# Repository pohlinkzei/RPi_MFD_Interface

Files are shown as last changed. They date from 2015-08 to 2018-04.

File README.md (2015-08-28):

# RPi_MFD_Interface
Interface between RaspberryPi and VW MFD Radio Navigation System

The RPi_MFD_Interface is a Atmega16-based device to connect the
RaspberryPi with the CarAudio head unit. Its main purpose is to read the
buttons of the car audio and send it to the pi.  The second purpose is
to power the pi with control over booting up and shutting down of the
raspberry pi to prevent it killing the cars battery.

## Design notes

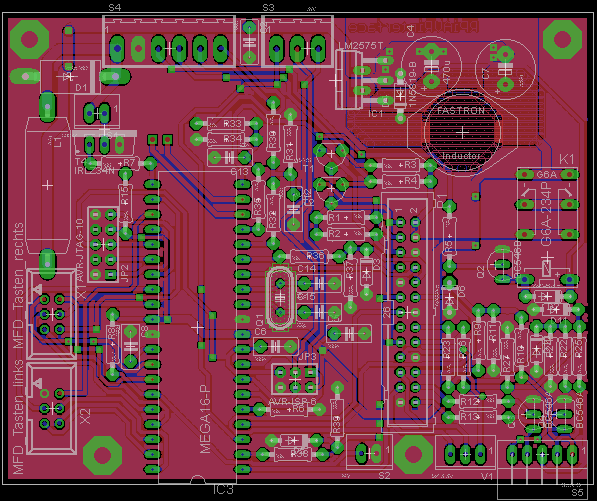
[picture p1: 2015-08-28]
layout/mega16_spg5Vonly.png

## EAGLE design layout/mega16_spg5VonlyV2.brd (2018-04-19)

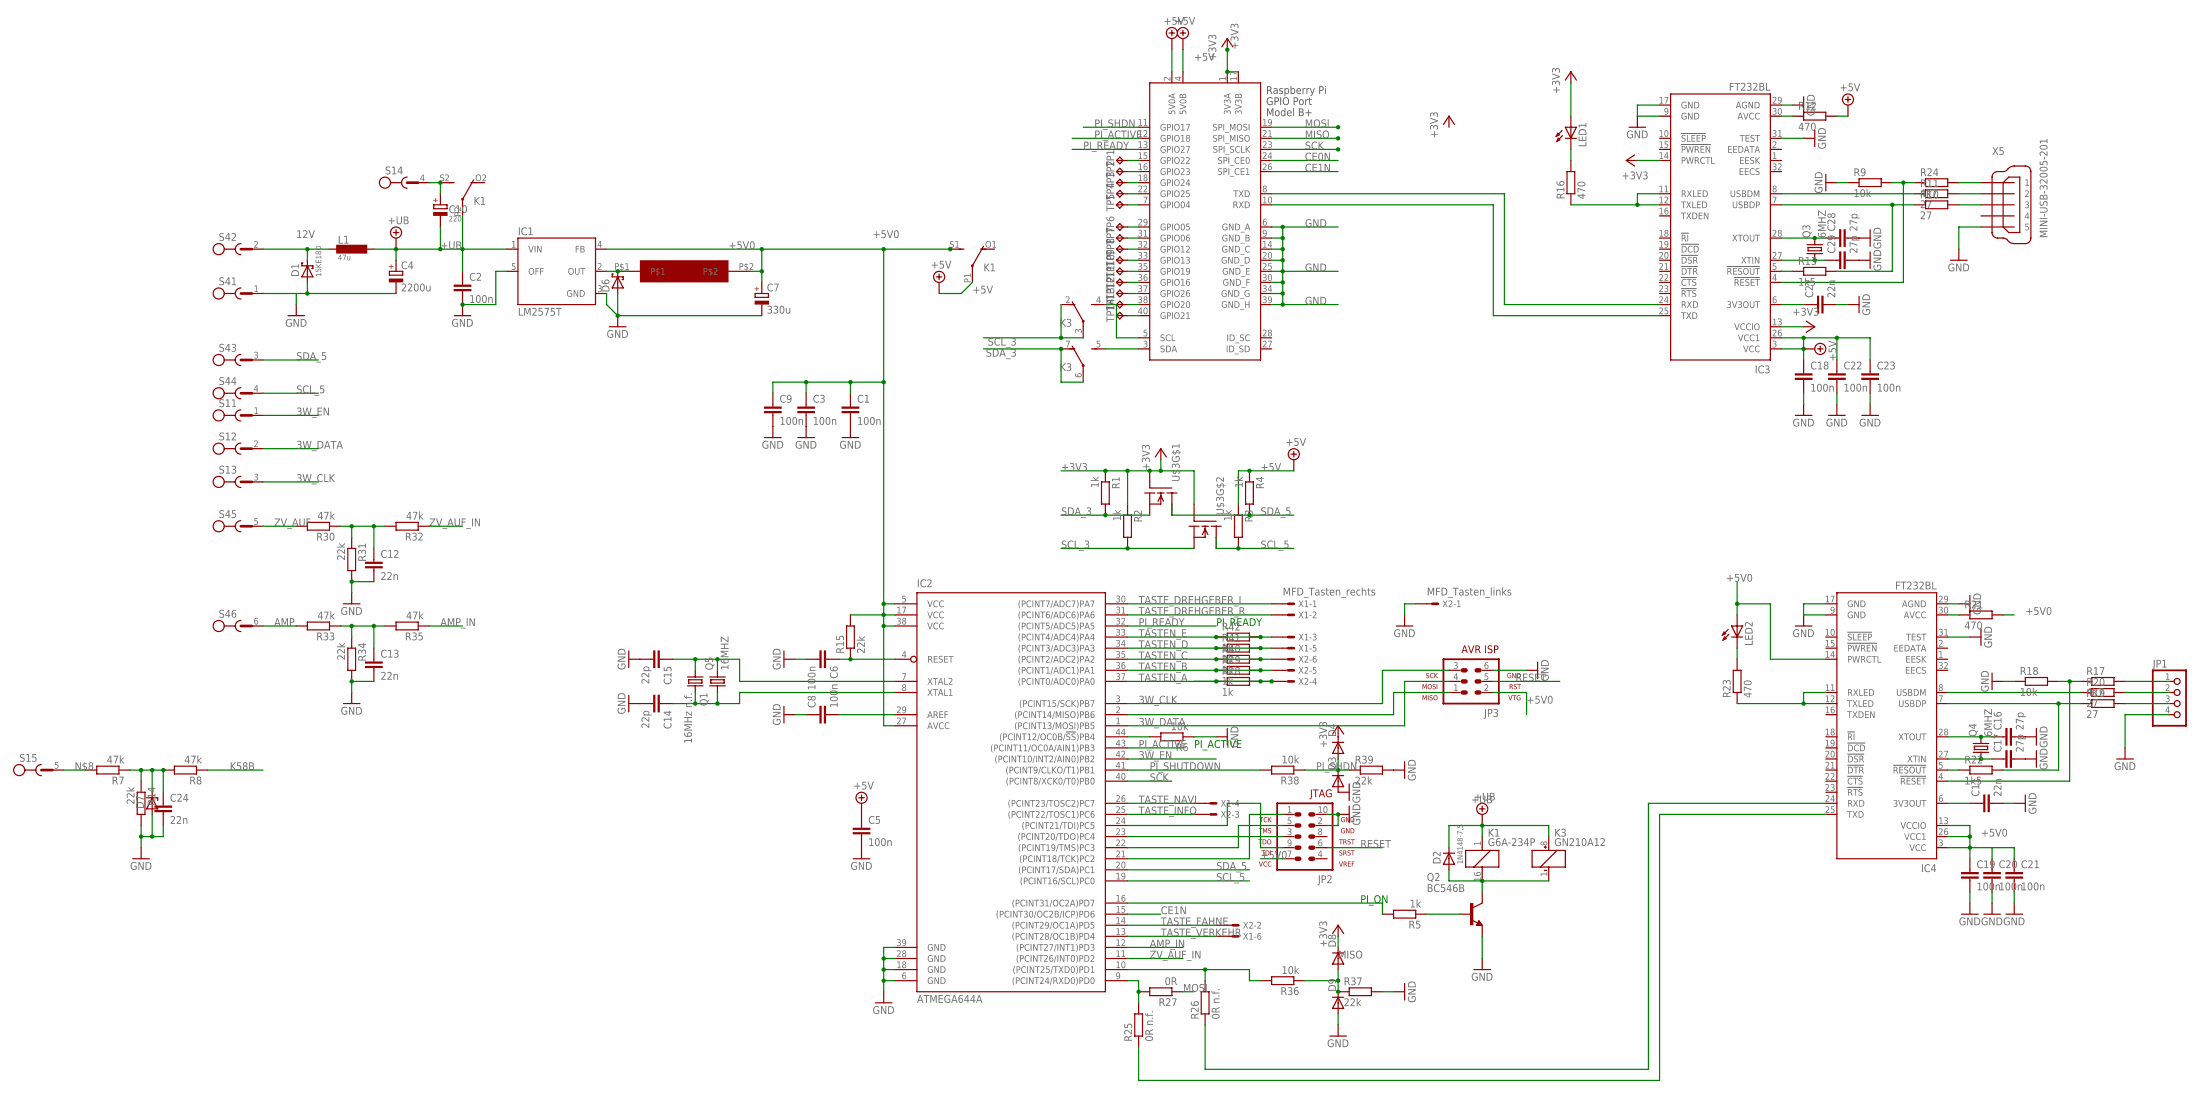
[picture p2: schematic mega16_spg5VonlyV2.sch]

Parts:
C1, C2, C3, C5, C6, C8, C9, C18, C19, C20, C21, C22, C23: 100n; C1206
C4: 2200u; E5-10,5
C7: 330u; E5-10,5
C10: 220; E2.5-5
C11, C12, C13, C24, C27: 22n; C1206
C14, C15: 22p; C1206
C16, C17, C28, C29: 27p; C1206
D1: 15KE18D; DO201T15
D2: 1N4148-7,5; DO35-7,5
D3, D4, D8, D9: DIODE-MICROMELF-W; MICROMELF-W
D6: SCHOTTKY-DIODEF126Z12; F126Z12
D7: ZPP-7.5; DO35-7,5
IC1: LM2575T; TO220-5
IC2: ATMEGA644A; TQFP44
IC3, IC4: FT232BL; LQFP32-7X7
JP1: PINHD-1X4_2.54; 1X04
JP2: AVR-JTAG-10
JP3: AVR-ISP-6
K1: G6A-234P
K3: GN210A12; GN-A
L1: 47u; MESC26
LED1, LED2: LEDP-LCC-2; P-LCC-2
Q1: 16MHz n.f.; HC49/S
Q2: BC546B; TO92-EBC
Q3, Q4: 6MHZ; CTS406
Q5: 16MHZ; CTS406
R1, R2, R3, R4, R5, R28, R29, R40, R41, R42: 1k; M1206
R6, R9, R18, R36, R38: 10k; M1206
R7, R8, R30, R32, R33, R35: 47k; M1206
R10, R11, R19, R20: 27; M1206
R12, R16, R21, R23: 470; M1206
R13, R22: 1k5; M1206
R14, R15, R31, R34, R37: 22k; M1206
R17, R24: 4k7; M1206
R25, R26: 0R n.f.; M1206
R27: 0R; M1206
R39: 22k; R1206
S1: CON-RIA-183-05; RIA-183-05
S4: CON-RIA-183-06; RIA-183-06
TP1, TP2, TP3, TP4, TP5, TP6, TP7, TP8, TP9, TP10, TP11, TP12, TP13, TP14: TPPAD1-13; P1-13
U$1: PISR
U$3: IRF7103; SO-8
X1: MFD_Tasten_rechts; 057-006-1
X2: MFD_Tasten_links; 057-006-1
X3: RASPI_GPIO_B+#_PIN; RASPI_GPIO_B+_PIN
X5: MINI-USB-32005-201; 32005-201

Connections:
3W_CLK: IC2.3 ((PCINT15/SCK)PB7), JP3.3, S1.3
3W_DATA: IC2.1 ((PCINT13/MOSI)PB5), JP3.4, S1.2
3W_EN: IC2.42 ((PCINT10/INT2/AIN0)PB2), S1.1
12V: D1.C, L1.1, S4.2
+3V3: D4.C, D8.C, IC3.13 (VCCIO), IC3.14 (PWRCTL), LED1.A, R1.1, R2.1, U$3.2 (G), U$3.4 (G), X3.1 (3V3A), X3.17 (3V3B)
+5V: C5.1, C18.1, C22.1, C23.1, IC3.3 (VCC), IC3.26 (VCC1), K1.P1, R3.1, R4.1, R12.2, X3.2 (5V0A), X3.4 (5V0B)
+5V0: C1.1, C3.1, C7.+, C9.1, C19.1, C20.1, C21.1, IC1.4 (FB), IC2.5 (VCC), IC2.17 (VCC), IC2.27 (AVCC), IC2.38 (VCC), IC4.3 (VCC), IC4.13 (VCCIO), IC4.14 (PWRCTL), IC4.26 (VCC1), JP2.7, JP3.2, K1.S1 (S), LED2.A, R15.2, R21.2, U$1.P$2
+UB: C2.1, C4.+, C10.-, D2.C, IC1.1 (VIN), K1.1, K1.P2, K3.8 (+), L1.2
AMP: R33.2, S4.6
AMP_IN: IC2.12 ((PCINT27/INT1)PD3), R35.1
CE0N: X3.24 (SPI_CE0)
CE1N: IC2.15 ((PCINT30/OC2B/ICP)PD6), X3.26 (SPI_CE1)
GND: C1.2, C2.2, C3.2, C4.-, C5.2, C6.2, C7.-, C8.1, C9.2, C11.2, C12.2, C13.2, C14.2, C15.2, C16.2, C17.2, C18.2, C19.2, C20.2, C21.2, C22.2, C23.2, C24.2, C27.2, C28.2, C29.2, D1.A, D3.A, D6.A, D7.A, D9.A, IC1.3 (GND), IC1.5 (OFF), IC2.6 (GND), IC2.18 (GND), IC2.28 (GND), IC2.39 (GND), IC3.9 (GND), IC3.17 (GND), IC3.29 (AGND), IC3.31 (TEST), IC4.9 (GND), IC4.17 (GND), IC4.29 (AGND), IC4.31 (TEST), JP1.4, JP2.2, JP2.10, JP3.6, Q2.E, R6.1, R9.1, R14.2, R18.1, R31.2, R34.2, R37.2, R39.2, S4.1, X2.1, X3.6 (GND_A), X3.9 (GND_B), X3.14 (GND_C), X3.20 (GND_D), X3.25 (GND_E), X3.30 (GND_F), X3.34 (GND_G), X3.39 (GND_H), X5.5
K58B: R8.1
MISO: D8.A, D9.C, R36.1, R37.1, X3.21 (SPI_MISO)
MOSI: R27.1, X3.19 (SPI_MOSI)
unnamed: C10.+, K1.S2 (S), S1.4
unnamed: D2.A, K1.16 (2), K3.1 (-), Q2.C
unnamed: IC3.24 (RXD), X3.8 (TXD)
unnamed: C24.1, D7.C, R7.1, R8.2, R14.1
unnamed: D6.C, IC1.2 (OUT), U$1.P$1
unnamed: C15.1, IC2.7 (XTAL2), Q1.1, Q5.3 (2)
unnamed: C8.2, IC2.29 (AREF)
unnamed: R7.2, S1.5
unnamed: IC3.25 (TXD), X3.10 (RXD)
unnamed: IC2.10 ((PCINT25/TXD0)PD1), R26.2, R36.2
unnamed: IC2.21 ((PCINT18/TCK)PC2), JP2.1
unnamed: IC2.22 ((PCINT19/TMS)PC3), JP2.5
unnamed: Q2.B, R5.1
unnamed: IC2.44 ((PCINT12/OC0B/!SS!)PB4), R6.2
unnamed: IC2.23 ((PCINT20/TDO)PC4), JP2.3
unnamed: IC2.16 ((PCINT31/OC2A)PD7), R5.2
unnamed: IC2.24 ((PCINT21/TDI)PC5), JP2.9
unnamed: C11.1, IC4.6 (3V3OUT)
unnamed: IC3.11 (RXLED), IC3.12 (TXLED), R16.1
unnamed: IC2.2 ((PCINT14/MISO)PB6), JP3.1
unnamed: LED1.C, R16.2
unnamed: IC4.7 (USBDP), R19.1, R22.2
unnamed: IC4.8 (USBDM), R20.1
unnamed: JP1.1, R17.2
unnamed: IC4.4 (!RESET), R17.1, R18.2
unnamed: JP1.3, R19.2
unnamed: JP1.2, R20.2
unnamed: IC4.30 (AVCC), R21.1
unnamed: IC4.5 (!RESOUT), R22.1
unnamed: C17.1, IC4.27 (XTIN), Q4.1
unnamed: C16.1, IC4.28 (XTOUT), Q4.3 (2)
unnamed: IC4.24 (RXD), R26.1
unnamed: IC4.25 (TXD), R25.1
unnamed: IC4.11 (RXLED), IC4.12 (TXLED), R23.1
unnamed: LED2.C, R23.2
unnamed: IC2.9 ((PCINT24/RXD0)PD0), R25.2, R27.2
unnamed: K3.5 (S), X3.3 (SDA)
unnamed: TP14.1, X3.40 (GPIO21)
unnamed: K3.4 (S), X3.5 (SCL)
unnamed: TP13.1, X3.38 (GPIO20)
unnamed: TP12.1, X3.37 (GPIO26)
unnamed: TP11.1, X3.36 (GPIO16)
unnamed: TP10.1, X3.35 (GPIO19)
unnamed: TP9.1, X3.33 (GPIO13)
unnamed: C14.1, IC2.8 (XTAL1), Q1.2, Q5.1
unnamed: TP8.1, X3.32 (GPIO12)
unnamed: TP7.1, X3.31 (GPIO06)
unnamed: TP6.1, X3.29 (GPIO05)
unnamed: TP1.1, X3.15 (GPIO22)
unnamed: C12.1, R30.1, R31.1, R32.2
unnamed: TP2.1, X3.16 (GPIO23)
unnamed: C13.1, R33.1, R34.1, R35.2
unnamed: TP3.1, X3.18 (GPIO24)
unnamed: R10.2, X5.3
unnamed: R11.2, X5.2
unnamed: IC3.30 (AVCC), R12.1
unnamed: IC3.5 (!RESOUT), R13.1
unnamed: C27.1, IC3.6 (3V3OUT)
unnamed: IC3.7 (USBDP), R10.1, R13.2
unnamed: IC3.8 (USBDM), R11.1
unnamed: R24.2, X5.1
unnamed: IC3.4 (!RESET), R9.2, R24.1
unnamed: C29.1, IC3.27 (XTIN), Q3.1
unnamed: C28.1, IC3.28 (XTOUT), Q3.3 (2)
unnamed: TP4.1, X3.22 (GPIO25)
unnamed: TP5.1, X3.7 (GPIO04)
PI_ACTIVE: IC2.43 ((PCINT11/OC0A/AIN1)PB3), X3.12 (GPIO18)
PI_READY: IC2.32 ((PCINT5/ADC5)PA5), X3.13 (GPIO27)
PI_SHDN: D3.C, D4.A, R38.1, R39.1, X3.11 (GPIO17)
PI_SHUTDOWN: IC2.41 ((PCINT9/CLKO/T1)PB1), R38.2
RESET: C6.1, IC2.4 (RESET), JP2.6, JP3.5, R15.1
SCK: IC2.40 ((PCINT8/XCK0/T0)PB0), X3.23 (SPI_SCLK)
SCL_3: K3.2 (O), K3.3, R2.2, U$3.3 (S)
SCL_5: IC2.19 ((PCINT16/SCL)PC0), R3.2, S4.4, U$3.5 (D1), U$3.6 (D)
SDA_3: K3.6, K3.7 (O), R1.2, U$3.1 (S)
SDA_5: IC2.20 ((PCINT17/SDA)PC1), R4.2, S4.3, U$3.7 (D), U$3.8 (D1)
TASTEN_A: IC2.37 ((PCINT0/ADC0)PA0), R28.1, R28.2, X2.4
TASTEN_B: IC2.36 ((PCINT1/ADC1)PA1), R29.1, R29.2, X2.5
TASTEN_C: IC2.35 ((PCINT2/ADC2)PA2), R40.1, R40.2, X2.6
TASTEN_D: IC2.34 ((PCINT3/ADC3)PA3), R41.1, R41.2, X1.5
TASTEN_E: IC2.33 ((PCINT4/ADC4)PA4), R42.1, R42.2, X1.3
TASTE_DREHGEBER_L: IC2.30 ((PCINT7/ADC7)PA7), X1.1
TASTE_DREHGEBER_R: IC2.31 ((PCINT6/ADC6)PA6), X1.2
TASTE_FAHNE: IC2.14 ((PCINT29/OC1A)PD5), X2.2
TASTE_INFO: IC2.25 ((PCINT22/TOSC1)PC6), X2.3
TASTE_NAVI: IC2.26 ((PCINT23/TOSC2)PC7), X1.4
TASTE_VERKEHR: IC2.13 ((PCINT28/OC1B)PD4), X1.6
ZV_AUF: R30.2, S4.5
ZV_AUF_IN: IC2.11 ((PCINT26/INT0)PD2), R32.1

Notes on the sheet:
PI_ACTIVE
PI_ON
PI_READY

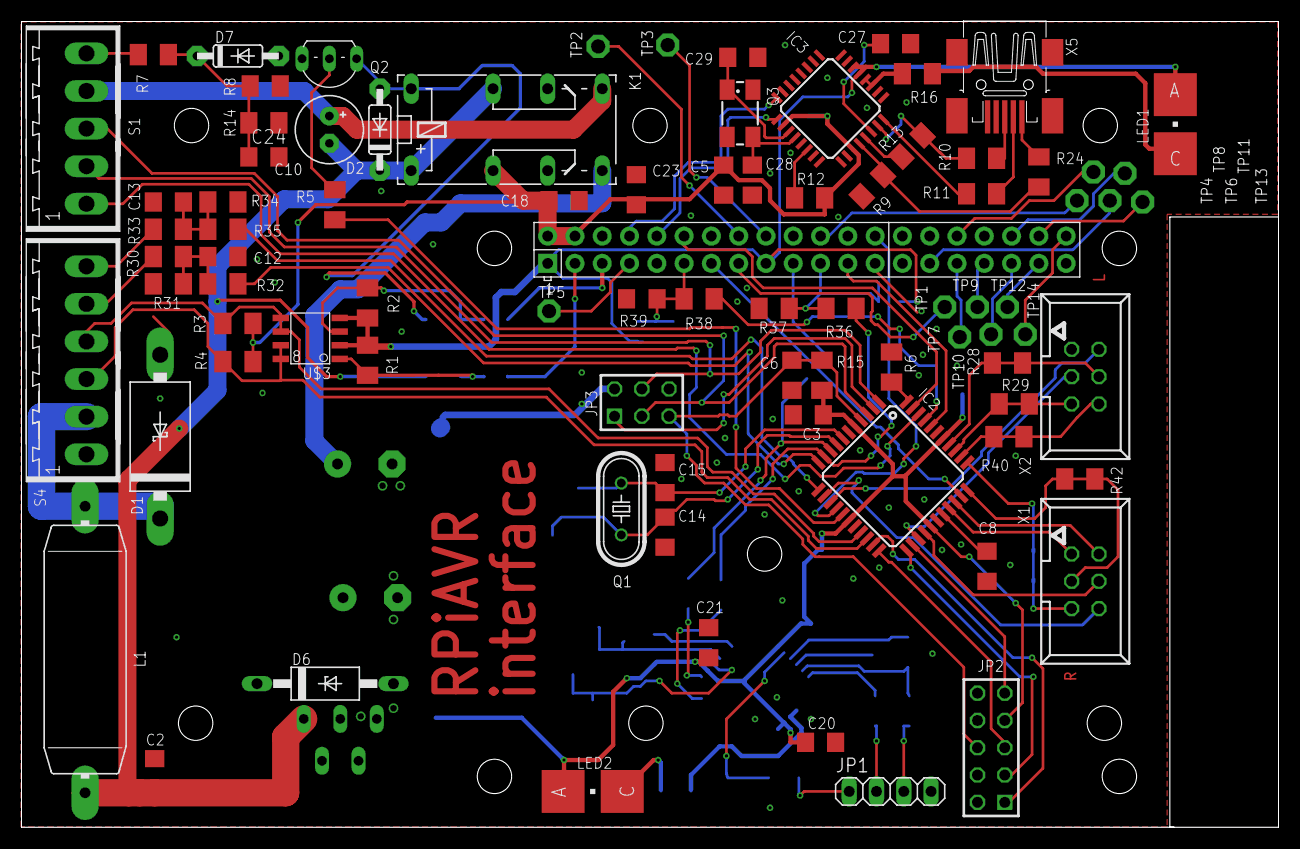
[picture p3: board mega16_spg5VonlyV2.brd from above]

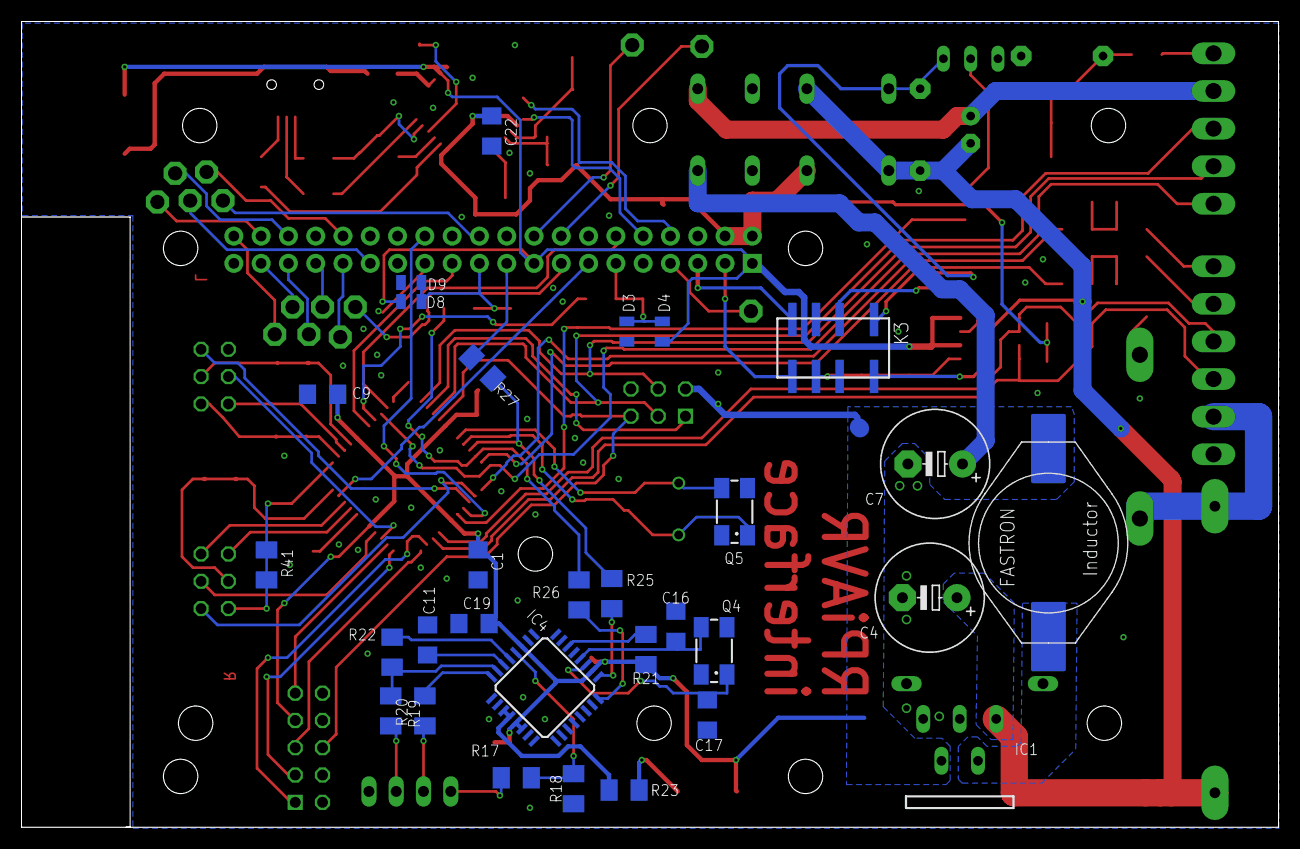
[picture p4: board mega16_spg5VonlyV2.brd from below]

Board: 2 copper layers, 117.0 x 75.0 mm, 117 parts (30 on the bottom side), 103 nets.

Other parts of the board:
U$2: EUROBOX

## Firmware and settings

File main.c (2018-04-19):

/*
 * main.c
 *
 * Created: 18.08.2014 16:45:53
 *  Author: Hubert
 */ 

#include <avr/io.h>
#include <stdbool.h>
#include <util/delay.h>
#include <avr/sleep.h>
#include <avr/interrupt.h>
#include <string.h>
#include "main.h"
#include "adc.h"
#include "spi.h"
#include "uart.h"

#include "buttons.h"
#include "rotary.h"

#define WAIT 250

extern volatile buttons_t buttons, buttons_old, buttons_vold;
volatile bool mfd_active = false;
volatile uint16_t pi_shutdown_count = 0;
volatile uint16_t pi_start_count = 0;
volatile uint8_t data_3lb[20];
volatile bool status = false;
uint8_t count_3lb = 0;
volatile uint32_t spi_timeout;
volatile uint16_t mp_cnt = 0;
volatile bool buttons_active = false;
volatile uint8_t buttons_active_count = 0;
volatile int32_t ZV_count;
volatile bool ready_3lb = false;
volatile uint8_t count_3lb_max = 0xFF;
volatile bool shutdown_irq = false;
volatile bool dont_start = false;

void timer1_init(void){
	TCCR1B |= (1<<WGM12) | (1<<CS11) | (1<<CS10);     // CTC, XTAL / 64
	OCR1A = (uint8_t)(XTAL / 64.0 * 1e-3 - 0.5);   // 1ms
	TIMSK1 |= 1<<OCIE1A;
}

void pi_shutdown_init(void){
	PISTARTPDDR |= (1<<PISTART);
	PIDDR |= (1<<PISHUTDOWN);
	pi_shutdown_count = 0;
}

void pi_shutdown_task(void){
	if(!(PISTARTPORT & (1<<PISTART))) return; // pi ausgeschaltet? dann zurück!
	//pi herunterfahren
	if(PIPORT & (1<<PISHUTDOWN)){
		// pi hat shutdown signal bekommen: ist er schon aus?
		if(PIPIN & (1<<PIACTIVE)){
			//noch an... da machen wir nix.
			return;
		}
		//hier isser schon aus.
		PIPORT &= ~(1<<PISHUTDOWN);
		_delay_ms(10000);//sicherheit
		PISTARTPORT &= ~(1<<PISTART);// und abschalten
		_delay_ms(10000);//sicherheit
	}else{
		// pi ist an - soll jetzt abgeschaltet werden
		if(!(PIREADYPIN & (1<<PIREADY))){
			uint8_t x = 0;
			do{
				USART_Transmit(0xFF); // MFD ausgeschaltet. Der Pi m�ge seine Arbeit einstellen.
				_delay_ms(200);
				x++;
				if(x>50) break;
			}while(PIREADYPIN & (1<<PIREADY));
		}
		PIPORT |= (1<<PISHUTDOWN);
	}
}

void init_3lb(void){
	spi_init(false,1,0);
}

void start_pi(void){
	if(dont_start) return;
	if(!(PISTARTPORT & (1<<PISTART))){ 
		cli();
		int i = 0;
		PIPORT &= ~(1<<PISHUTDOWN);
		_delay_ms(100);
		PISTARTPORT |= (1<<PISTART);
		for(;i<30;i++){
			_delay_ms(1000);
		}		
		sei();
	}	
}

void uart_task(){
//*
	if(buttons_old._1) USART_Transmit('1');
	if(buttons_old._2) USART_Transmit('2');
	if(buttons_old._3) USART_Transmit('3');
	if(buttons_old._4) USART_Transmit('4');
	if(buttons_old._5) USART_Transmit('5');
	if(buttons_old._6) USART_Transmit('6');
	if(buttons_old.next) USART_Transmit('n');
	if(buttons_old.prev) USART_Transmit('p');
	if(buttons_old.eject) USART_Transmit('e');
	if(buttons_old.tim) USART_Transmit('t');
	if(buttons_old.info) USART_Transmit('i');
	if(buttons_old.as) USART_Transmit('a');
	if(buttons_old.scan) USART_Transmit('s');
	if(buttons_old.flag) USART_Transmit('f');
	if(buttons_old.light) USART_Transmit('l');
	if(buttons_old.navi) USART_Transmit('N');
	if(buttons_old.back) USART_Transmit('b');
	if(buttons_old.audio) USART_Transmit('A');
	if(buttons_old.tone) USART_Transmit('T');
	if(buttons_old.left_right){
		int8_t c = buttons_old.left_right;
		if(c > 0){
			//while(c--){
				USART_Transmit('+');
				_delay_us(WAIT);
				USART_Transmit(c);
				_delay_us(WAIT);
				USART_Transmit('0');
			//}
		}else{
			//while(c++){
				c *= -1;
				USART_Transmit('-');
				_delay_us(WAIT);
				USART_Transmit(c);
				_delay_us(WAIT);
				USART_Transmit('0');
			//}							
		}
	}	
	if(buttons_old.enter) USART_Transmit('E');
	if(buttons_old.traffic){ 
		
		if(PIPIN & (1<<PIACTIVE)){
			PIPORT |= (1<<PISHUTDOWN);
			_delay_ms(1000);
			PIPORT &= ~(1<<PISHUTDOWN);
			dont_start = true;
		}else{
			PISTARTPORT &= ~(1<<PISTART);
			_delay_ms(1000);
			dont_start = false;
		}

	}
	if(buttons.next == false && buttons.prev == false && buttons.eject == false && buttons.tim == false && buttons.info == false && buttons.as == false && buttons.scan == false && buttons._1 == false &&	buttons._2 == false && buttons._3 == false && buttons.flag == false && buttons.light == false && buttons.navi == false && buttons.back == false && buttons.audio == false && buttons.tone == false && buttons.left_right == 0 && buttons.enter == false && buttons._4 == false && buttons._5 == false && buttons._6 == false && buttons.traffic == false){
		USART_Transmit('0');
	}
	buttons_old = buttons;
//*/	
	buttons_init();
	
}

uint8_t aux_check(void){
	//  01234567 89012345
	// [  AUX            ] 
	// [  AUX          TP]
	// [  AUX    INFO  TP]
	//return AUX;
	//if(ready_3lb){
		if(strncmp( (char*) &data_3lb[1], "  AUX   ", 8) == 0){
			if(strncmp( (char*) &data_3lb[9], "INFO  TP", 8) == 0){
				return AUX_INFO;
			}else{
				return AUX;
			}	
		}else{
			spi_init(false, 0,0);
			return NOT_AUX;
		}
	//}
	return AUX_NR; // not ready
}	
	

int main(void){
	PORTB &= ~(1<<PB0);
	adc_init();
	init_3lb();
	timer1_init();
    buttons_init();
	pi_shutdown_init();
	set_sleep_mode(SLEEP_MODE_IDLE);
	ZV_count = 10;
	USART_Init(MYUBRR);
	sei();
	while(1){
		//*
		if(buttons_active){
			if((AMP_PIN & (1<<AMP_ON))){
				start_pi();
				switch(aux_check()){
					case AUX:{
						buttons_task();
						uart_task();
						break;
					}
					case NOT_AUX:{
						USART_Transmit(0x01);
						_delay_ms(250);
						uint8_t i;
						for(i=1; i<17; i++){
							USART_Transmit(data_3lb[i]);
							_delay_ms(25);
						}
						USART_Transmit(0x00);
						_delay_ms(250);
						break;
					}
					case AUX_INFO:{
						USART_Transmit(0x01);
						_delay_ms(250);
						break;
					}
				}
				mfd_active = true;
			}else{
//				pi_shutdown_task();
//*
				if(ZV_PIN & (1<<ZV_ZU)){
					pi_shutdown_task();
				}else{
					start_pi();
					USART_Transmit(0x02);
					_delay_ms(250);
				}
//*/
			}
			buttons_active = false;
		}
		if(!(PISTARTPORT & (1<<PISTART))){
			//sleep_mode();
			buttons_active = true;
		}	
		//*/		
    }
	return 0;
}

ISR(TIMER1_COMPA_vect){// 1ms Timer
	pi_start_count++;
	pi_shutdown_count++;
	mp_cnt++;
	if(mp_cnt == 100){
		mp_cnt = 0;
		buttons_active = true;
	}
}

ISR(SPI_STC_vect){
	//*
	uint8_t data = 0xFF-SPDR;
	SPSR &= ~(1<<SPIF);
	if(data == (0x81) || data == 0xC1){// data == 0x56 || data == 0x53 für navi frames
		uint8_t i = 0;
		_delay_us(150);
		PORT_3LB |= (1<<EN);
		DDR_3LB |= (1<<EN);
		SPSR &= ~(1<<SPIF);
		uint16_t timeout_us = 500;
		while(!(SPSR & (1<<SPIF)) && timeout_us > 0){
			_delay_us(10);
			timeout_us -= 20;	
		}
		data =  0xFF-SPDR;
		_delay_us(20);
		DDR_3LB &= ~(1<<EN);
		PORT_3LB &= ~(1<<EN);
		while(data--){
			_delay_us(150);
			PORT_3LB |= (1<<EN);
			DDR_3LB |= (1<<EN);		
			SPSR &= ~(1<<SPIF);
			timeout_us = 500;
			while(!(SPSR & (1<<SPIF)) && timeout_us > 0){
				_delay_us(10);
				timeout_us -= 20;	
			}
			data_3lb[i++] =  0xFF-SPDR;
			_delay_us(20);
			DDR_3LB &= ~(1<<EN);
			PORT_3LB &= ~(1<<EN);
		}
	}else if(data == 0xC3){
		if(data_3lb[1] == 0){
			PORT_3LB |= (1<<EN);
			DDR_3LB |= (1<<EN);
			_delay_us(3500);
			DDR_3LB &= ~(1<<EN);
			PORT_3LB &= ~(1<<EN);
			_delay_ms(2);
			PORT_3LB |= (1<<EN);
			DDR_3LB |= (1<<EN);
			_delay_us(3500);
			DDR_3LB &= ~(1<<EN);
			PORT_3LB &= ~(1<<EN);
		}
		ready_3lb = true;		
	}else{
		ready_3lb = false;
	}
	//*/
	DDR_3LB &= ~(1<<EN);
	PORT_3LB &= ~(1<<EN);
}
//ISR( TIMER0_COMP_vect )// 1ms for manual movement

ISR(USART0_RX_vect){/*
	uint8_t data = UDR;
	if(data == 0xFF){
		shutdown_irq = true;
		//mfd_active = true;
	}*/
}


ISR(INT0_vect){
	start_pi();
}

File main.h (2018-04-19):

#ifndef MAIN_H
#define MAIN_H
#ifndef F_CPU
#define F_CPU 16000000UL
#endif
#include <avr/io.h>
#include <stdbool.h>
#include <util/delay.h>
#include <avr/sleep.h>
#include <avr/interrupt.h>

// 3LB
#define PORT_3LB PORTB	
#define DDR_3LB	DDRB
#define EN		PB2 //INT2
#define DATA	PB5 //MOSI
#define CLK		PB7 //SCK
#define AUX		1
#define NOT_AUX	0
#define AUX_INFO 2
#define AUX_NR 3

// Shutdown Pi
#define PIPORT PORTB
#define PIPIN PINB
#define PIDDR DDRB
#define PIACTIVE PB4
#define PISHUTDOWN PB1
#define PIREADYPORT PORTA
#define PIREADYDDR DDRA
#define PIREADYPIN PINA
#define PIREADY PA5

// Start Pi
#define PISTARTPDDR DDRD
#define PISTARTPORT PORTD
#define PISTART PD7 

#define ZV_PIN	PIND
#define ZV_ZU	PD2

#define AMP_PIN PIND
#define AMP_ON PD3

uint8_t read_3lb(void);

extern volatile uint16_t pi_shutdown_count;
extern volatile uint16_t pi_start_count;
extern volatile uint8_t data_3lb[20];
extern volatile bool status;
extern uint8_t count_3lb;
extern volatile uint32_t spi_timeout;

#endif

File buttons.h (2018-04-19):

#ifndef BUTTONS_H
#define BUTTONS_H


#include <avr/io.h>
#include <stdbool.h>
#include <string.h>
#include "adc.h"

// MFD Buttons
#define BUTTON_DDR DDRC
#define BUTTON_PORT PORTC
#define BUTTON_PIN PINC
#define BUTTON_NAVI PC7
#define BUTTON_FAHNE PD5
#define BUTTON_INFO PC6
#define BUTTON_VERKEHR PD4
#define BUTTONS_A PA0
#define BUTTONS_B PA1
#define BUTTONS_C PA2
#define BUTTONS_D PA3
#define BUTTONS_E PA4

	// 3,3V 168 153 - 183
	// 2,6V 133 118 - 148
	// 1,8V 92 107 - 137
	// 0,9V 46 31 - 61

#define UPPER3V3 183
#define LOWER3V3 153
#define UPPER2V6 148
#define LOWER2V6 118
#define UPPER1V8 107
#define LOWER1V8 77
#define UPPER0V9 61
#define LOWER0V9 31
#define UPPER0V0 25

typedef struct but{
	bool next;
	bool prev;
	bool eject;
	bool tim;
	bool info;
	bool as;
	bool scan;
	bool _1;
	bool _2;
	bool _3;
	bool flag;
	bool light;
	bool navi;
	bool back;
	bool audio;
	bool tone;
	int8_t left_right;
	bool enter;
	bool _4;
	bool _5;
	bool _6;
	bool traffic;
}buttons_t;


extern volatile buttons_t buttons, buttons_old;

void buttons_init(void);
void buttons_task(void);

#endif

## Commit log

2015-08-28 Initial commit
    The RPi_MFD_Interface is a Atmega16-based device to connect the
    RaspberryPi with the CarAudio head unit. Its main purpose is to read the
    buttons of the car audio and send it to the pi. The second purpose is
    to power the pi with control over booting up and shutting down of the
    raspberry pi to prevent it killing the cars battery.
    [adc.c, buttons.h, main.c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]
2015-08-28 Add: Layout
    [mega16_spg5Vonly.brd, mega16_spg5Vonly.sch]
2015-08-28 Fix: SPI-Connection
2015-10-28 update: change to device tree overlay for the raspberry pi
2016-05-24 add restart button
2018-04-19 Add HW design
    [mega16_spg5VonlyV2.brd, mega16_spg5VonlyV2.sch]
